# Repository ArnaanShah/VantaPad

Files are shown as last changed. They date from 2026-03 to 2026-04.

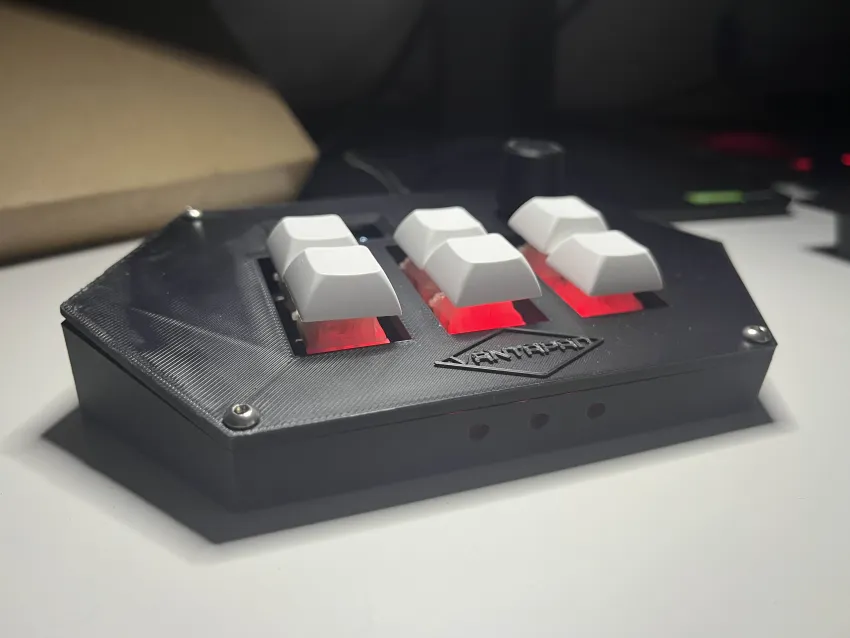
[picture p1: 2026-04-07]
ImagesVideos/IMG_0888.webp

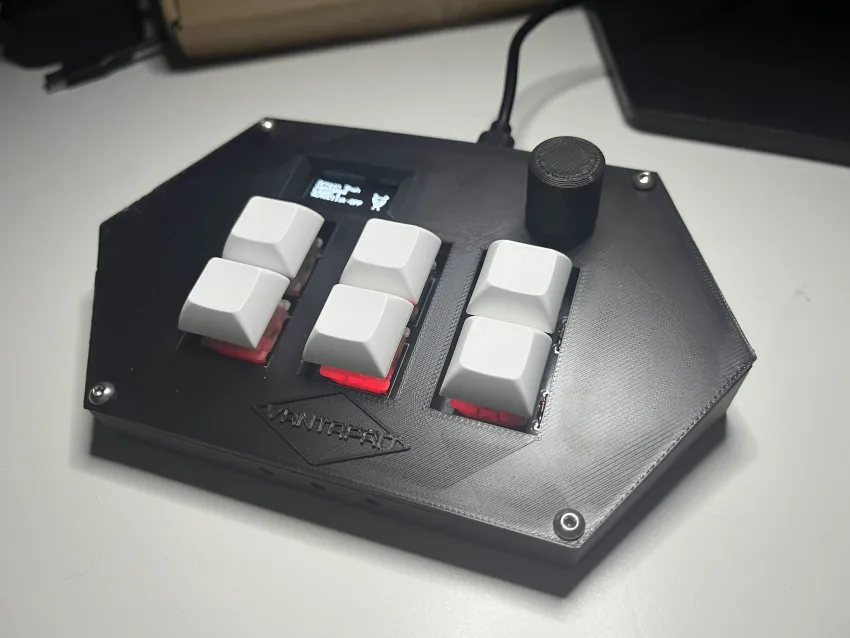
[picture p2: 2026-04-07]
ImagesVideos/IMG_0889.webp

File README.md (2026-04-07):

# VantaPad 👽

VantaPadLogoImage
isoCompletedBuild

A Hackpad made as a part of [Hackclub's Blueprint](https://blueprint.hackclub.com/home) program. VantaPad is a sleek black macropad I will use for controlling simple functions on my computer that I currently do by hand. It is one of my first hardware projects and I built it so I could learn many valuable skills such as schematic design, PCB design, Firmware programming, and more.

## How to use
**Brief intro on how to get up and running with VantaPad**

1. Order all the parts based off the BOM
2. Solder your electrical components onto your PCB based on the models and schematics
3. Assemble your case using the hardware provided
4. Plug your microcontroller into your computer and flash your firmware
5. You're done! Read the rest of this doc to understand what it can do.

## Features 
**What I included on my build.**

- Black Case - A case in the shape of a hexagon with the logo embossed near the bottom.
- 6 Keys in 3x2 layout - Top row is used for resetting screen, taking screenshots, and play/pause. Bottom row has macros for reopening tabs, auto clicking, and cycling layers.  
- 3 RGB LEDs - Lights up a constant looping effect that fades in and out through the case. 
- Rotary Encoder - Layer 1 is Volume, Layer 2 is Tab Scrolling, Layer 3 is undo/redo
- 128x32 OLED Display - Shows important info like what layer you're on and auto clicker status. Also, shows idle animations and reactions when you press a key.
  
## PCB 
**The design around my PCB. This Includes the schematic I made, the PCB, and more.** 

I designed my PCB in KiCad 9.0! It was fun to use this app because it was pretty beginner friendly and intuitive. It also had some extra built in features so I didn't have to download another app.

Schematic: 

SchematicImage 

PCB:

PCBImage

3d VIEW:

Top3dPCBImage
Bottom3dPCBImage

I used KiCad's built-in Image Converter to make a footprint of my logo:

LogoFootprintImage

## CAD
**The CAD model I made.**

I modeled this project in Fusion 360 because I've used it before. My plan is that I can assemble the whole thing with 6 screws. 4 on the actual case and 2 connecting the PCB and PCB plate to the case. I added a 10 degree tilt to make it easier to see. There are 3 separate 3d printed parts; the top, the plate, and the bottom. The top has the VantaPad logo on it because it looks lit. 😎

Pictures 📸:
VantaPadAngledImage
VantaPadIsometricImage
VantaPadFrontTopImage
VantaPadTopImage

## Firmware 
**Insight into the Firmware**

I wrote all the firmware in QMK. I spent a long time fixing problems when writing the code. These problems were things like the firmware not compiling, not knowing how to use all my extra features, and more. The QMK docs can be confusing but I found many resources online to help me. 

- The 6 keys are mapped as shown but can be easily changed
```
║ Screen Reset ║ Screenshot   ║ Play/Pause  ║

║ Reopen Tab   ║ Auto Clicker ║ Layer Cycle ║
```
```// ---------- Keymaps ----------
const uint16_t PROGMEM keymaps[][MATRIX_ROWS][MATRIX_COLS] = {
    [_BASE] = LAYOUT(
        RESET_SCREEN, SCREENSHOT, KC_MPLY, KC_MUTE, // Top row + Encoder Button
        REOPEN_TAB, AUTO_CLICKER, KC_CYCLE_LAYERS
    ),
};
```
- The rotary encoder controls volume on the first layer, scrolls through browser tabs on the second layer, and undos/redos on the third layer.
  - When you press down on the encoder it always mutes the volume
```
const uint16_t PROGMEM encoder_map[][1][2] = {
    [_BASE]   = { ENCODER_CCW_CW(KC_VOLD, KC_VOLU) },
    [_LAYER1] = { ENCODER_CCW_CW(LCTL(KC_PGUP), LCTL(KC_PGDN)) },
    [_LAYER2] = { ENCODER_CCW_CW(LCTL(KC_Z), LCTL(KC_Y)) },
};
```
- The OLED has 2 animations. Animation 1 is the constant looping animation where my alien is "breathing" with occasional blinks. Animation 2 starts when any key is pressed and it basically makes the alien look surprised and have a lightning bolt above his head. 
OLEDAnimationImage

- The OLED also has some info on the left of the animation. This includes what layer it is currently using, whether the auto clicker is on, the label "Vantapad", and also my name. 
```
oled_set_cursor(0, 0);
    oled_write_P(PSTR("Arnaan Shah"), false);

    oled_set_cursor(0, 1);
    oled_write_P(PSTR("Vantapad"), false);

    oled_set_cursor(0, 2);
    switch (get_highest_layer(layer_state)) {
        case _BASE:   oled_write_P(PSTR("Layer 1"), false); break;
        case _LAYER1: oled_write_P(PSTR("Layer 2"), false); break;
        case _LAYER2: oled_write_P(PSTR("Layer 3"), false); break;
    }

    oled_set_cursor(0, 3);
    if (auto_clicker_active) {
        oled_write_P(PSTR("AutoClick:ON "), false);
    } else {
        oled_write_P(PSTR("AutoClick:OFF"), false);
    }
```

- The RGB LEDS are set to display red and cycle a constant breathing animation
```
void keyboard_post_init_user(void) {
    rgblight_enable_noeeprom();
    rgblight_sethsv_noeeprom(0, 255, 100);
    rgblight_mode_noeeprom(RGBLIGHT_MODE_BREATHING + 1); 
}
```
## BOM
**What to buy to build this macropad. Does not include all the tools required to build it.**

| Name | Amount | Link |
|---|---|---|
| Cherry MX Switches | 6 | [Adafruit](https://www.adafruit.com/product/4952)|
| DSA Keycaps | 6 | [Adafruit](https://www.adafruit.com/product/4997?srsltid=AfmBOopDyFMg5RxxF-Evr6nBGQDyHVTH-dyfbuGdqPaHn7PWQv5c8-_Q) |
| M3 16mm SHCS Bolts | 5 | [Accu Components](https://accu-components.com/us/metric-cap-head-screws/3822-SSCF-M3-16-A2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) |
| M3 12mm SHCS Bolt | 1 | [Accu Components](https://accu-components.com/us/metric-cap-head-screws/3820-SSCF-M3-12-A2) |
| M3 Hex Nuts | 6 | [Accu Components](https://accu-components.com/us/hexagon-nuts/7888-HPN-M3-A2) |
| In4148 DO-35 Diodes | 7 | [Adafruit](https://www.adafruit.com/product/1641?srsltid=AfmBOoragpyopdxH587co8w9Kl0W3cZMjn9bZIbP4UEYHfyiLFoC3nJv) |
| WS2812B RGB LEDS | 3 | [Adafruit](https://www.adafruit.com/product/4684?srsltid=AfmBOop-1QOhPkmYg3AzDhOUYgR5UXpQo03Vo2tT4txB9Lo8MBpf2Z1e) |
| 0.91" OLED Display | 1 | [Aliexpress](https://www.aliexpress.us/item/3256807215355950.html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)|
| EC11 Encoder | 1 | [Adafruit](https://www.adafruit.com/product/377)|
| Seeed Studio XIAO RP2040 | 1 | [Seeed Studio](https://www.seeedstudio.com/XIAO-RP2040-v1-0-p-5026.html) |
| 3d Printed Case | 1 | N/A |

## Extras 🪄
**Miscellaneous related things**

I made the logo design all in Figma and it's based off the "Space Alien" inside Halloween Stickers. 

It's honestly one of my favorite parts of the project because of how cute he is 😅

_

Here are some photos of my brainstorming process. It includes some (really) rough sketches in my notebook and also online. 



_I always start with doing things in my notebook and then move forward from there. It helps me get a very basic idea of what im going to do and how to accomplish it._


 
_I made this image afterwards just to get a better understanding of how I wanted it to look._

Changes I would still consider making down the line include: 
1. More Information displayed on the OLED - WPM, Time, Date, Volume
2. Adding more animations to the OLED - Spinning alien based on knob, startup screen
3. Making the RGB react - Flash on key press, blink when auto-clicker's active
4. Displaying the PCB through the case somehow

Some resources I used:
- [Joe Scotto's Youtube Channel](https://www.youtube.com/@joe_scotto) (LIFESAVER 🙏)
- [QMK Docs](https://docs.qmk.fm)
- [r/MechanicalKeyboards subreddit](https://www.reddit.com/r/MechanicalKeyboards/) 

# Thanks for reading! If you have any feedback, comments, or questions I would love to hear them and you can always reach out to me!
GoodbyeImage

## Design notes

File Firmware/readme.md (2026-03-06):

# vantapad

vantapad

A Hackpad made as a part of Hackclub's Blueprint program. VantaPad is a sleek black macropad I will use for controlling simple functions on my computer that I currently do by hand. It is one of my first hardware projects and it taught me many valuable skills such as schematic design, PCB design, Firmware programming, and more.

* Keyboard Maintainer: [Arnaan Shah](https://github.com/ArnaanShah)

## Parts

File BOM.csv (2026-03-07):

Name | Amount | Link
Cherry MX Switches | 6 | https://www.adafruit.com/product/4952
DSA Keycaps | 6 | https://www.adafruit.com/product/4997
M3 16mm SHCS Bolts | 5 | https://accu-components.com/us/metric-cap-head-screws/3822-SSCF-M3-16-A2
M3 12mm SHCS Bolt | 1 | https://accu-components.com/us/metric-cap-head-screws/3820-SSCF-M3-12-A2
M3 Hex Nuts | 6 | https://accu-components.com/us/hexagon-nuts/7888-HPN-M3-A2
In4148 DO-35 Diodes | 7 | https://www.adafruit.com/product/1641
WS2812B RGB LEDS | 3 | https://www.adafruit.com/product/4684
0.91 OLED Display | 1 | https://www.aliexpress.us/item/3256807215355950.html?src=google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
EC11 Encoder | 1 | https://www.adafruit.com/product/377
Seeed Studio XIAO RP2040 | 1 | https://www.seeedstudio.com/XIAO-RP2040-v1-0-p-5026.html
3d Printed Case | 1 | N/A

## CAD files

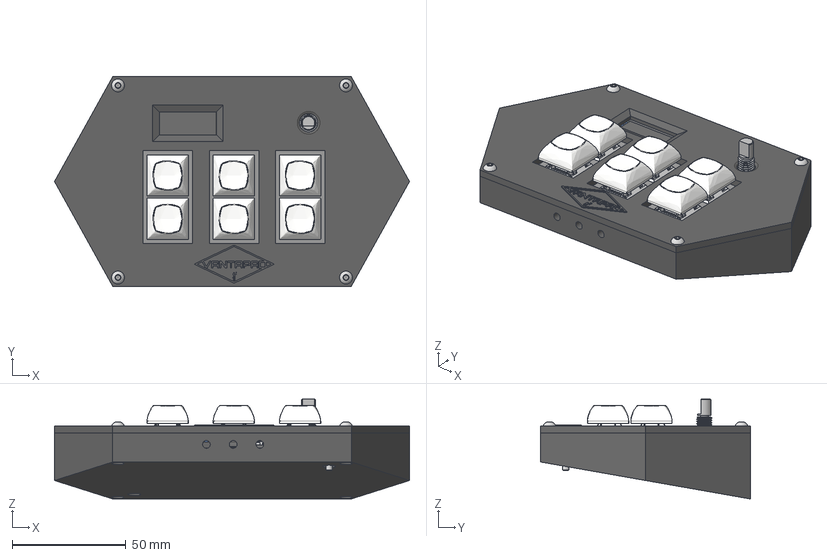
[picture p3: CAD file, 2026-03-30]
CAD/VantaPad v1.step
155.8 x 92.0 x 43.8 mm
MX_CAD x 6
PinHeader_1x04_P2.54mm_Vertical
OLED_0.91_128x32
Pin Header 4 x 1 TH 2.54mm Pitch
RESC-0603 x 13
2SD0601A
EC11
D_DO-35_SOD27_P7.62mm_Horizontal x 7
arnaansRealMacropad_silkscreen
arnaansRealMacropad_silkscreen_1
arnaansRealMacropad_soldermask
arnaansRealMacropad_soldermask_1
arnaansRealMacropad_PCB
MX Mount v1 x 6
type-c v2
smd_button v3
DOUT
DIN
VSS
VDD
smd_button v3(Mirror)
Logo
DIN EN ISO 7380-1 - M3 x 16 Steel 4.6 Plain x 6

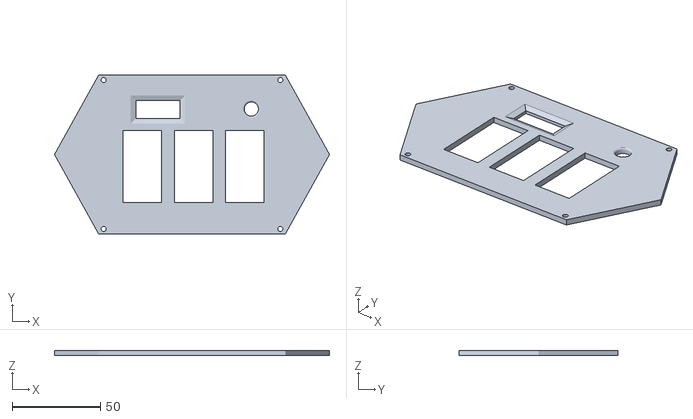
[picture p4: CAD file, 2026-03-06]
Production/VantaPadV1Top.stl
155.8 x 90.0 x 3.00

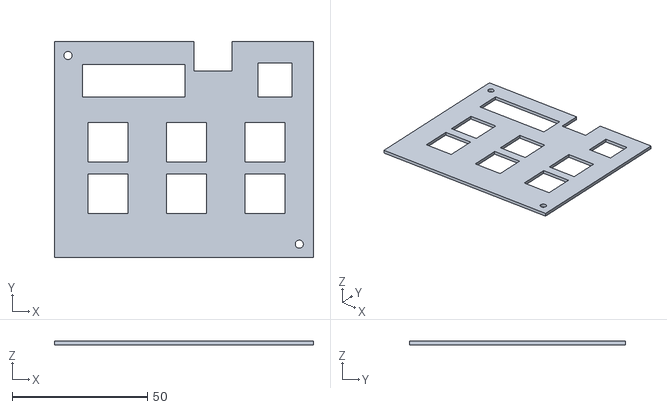
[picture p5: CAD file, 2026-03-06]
Production/VantaPadV1Plate.stl
95.8 x 80.0 x 1.50

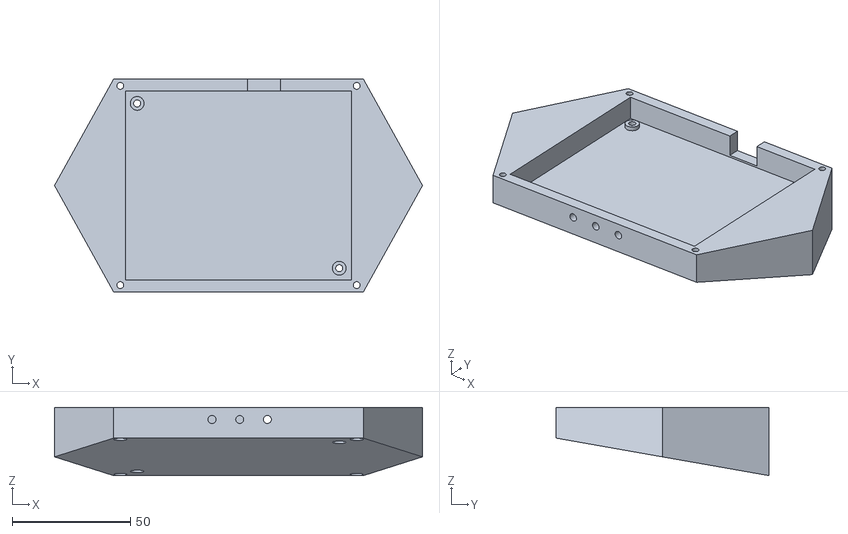
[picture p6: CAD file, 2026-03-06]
Production/VantaPadV1Bottom.stl
155.8 x 90.0 x 28.9

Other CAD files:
CAD/VantaPad v1.3mf

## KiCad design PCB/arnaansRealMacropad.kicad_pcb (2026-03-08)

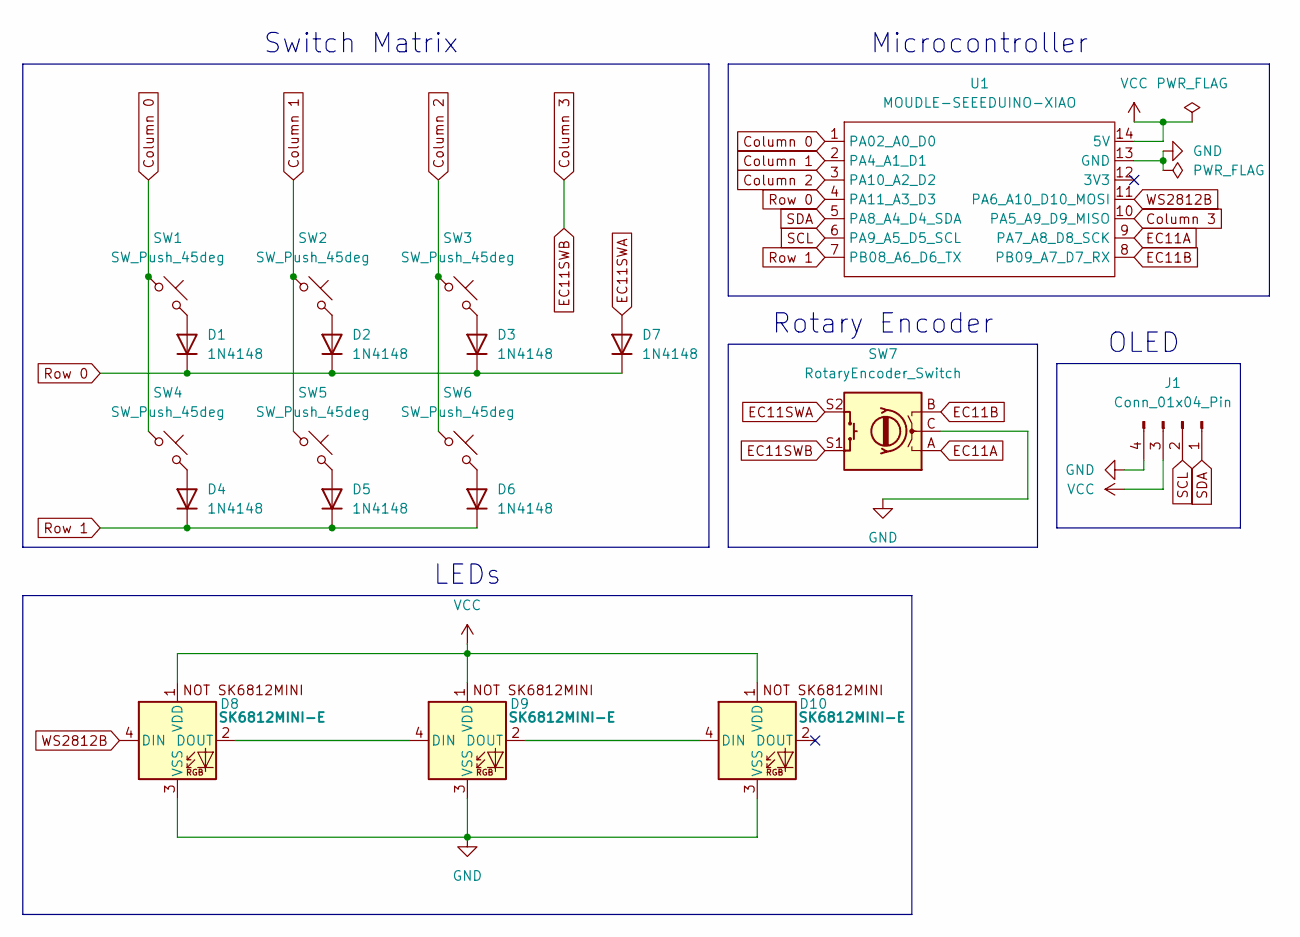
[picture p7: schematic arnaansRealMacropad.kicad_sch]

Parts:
D1, D2, D3, D4, D5, D6, D7: 1N4148; D_DO-35_SOD27_P7.62mm_Horizontal
D8, D9, D10: SK6812MINI-E; SK6812MINI-E_fixed
J1: Conn_01x04_Pin; PinHeader_1x04_P2.54mm_Vertical
SW1, SW2, SW3, SW4, SW5, SW6: SW_Push_45deg; SW_Cherry_MX_1.00u_PCB
SW7: RotaryEncoder_Switch; RotaryEncoder_Alps_EC11E-Switch_Vertical_H20mm
U1: MOUDLE-SEEEDUINO-XIAO; XIAO-Generic-Hybrid-14P-2.54-21X17.8MM

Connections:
Column 0: SW1.1, SW4.1, U1.1 (PA02_A0_D0)
Column 1: SW2.1, SW5.1, U1.2 (PA4_A1_D1)
Column 2: SW3.1, SW6.1, U1.3 (PA10_A2_D2)
Column 3: SW7.S1, U1.10 (PA5_A9_D9_MISO)
EC11A: SW7.A, U1.9 (PA7_A8_D8_SCK)
EC11B: SW7.B, U1.8 (PB09_A7_D7_RX)
EC11SWA: D7.2 (A), SW7.S2
GND: D8.3 (VSS), D9.3 (VSS), D10.3 (VSS), J1.4, SW7.C, U1.13 (GND)
unnamed: D1.2 (A), SW1.2
unnamed: D2.2 (A), SW2.2
unnamed: D3.2 (A), SW3.2
unnamed: D4.2 (A), SW4.2
unnamed: D5.2 (A), SW5.2
unnamed: D6.2 (A), SW6.2
unnamed: D8.2 (DOUT), D9.4 (DIN)
unnamed: D9.2 (DOUT), D10.4 (DIN)
Row 0: D1.1 (K), D2.1 (K), D3.1 (K), D7.1 (K), U1.4 (PA11_A3_D3)
Row 1: D4.1 (K), D5.1 (K), D6.1 (K), U1.7 (PB08_A6_D6_TX)
SCL: J1.2, U1.6 (PA9_A5_D5_SCL)
SDA: J1.1, U1.5 (PA8_A4_D4_SDA)
VCC: D8.1 (VDD), D9.1 (VDD), D10.1 (VDD), J1.3, U1.14 (5V)
WS2812B: D8.4 (DIN), U1.11 (PA6_A10_D10_MOSI)

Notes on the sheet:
Rotary Encoder
OLED
Microcontroller
Switch Matrix
LEDs

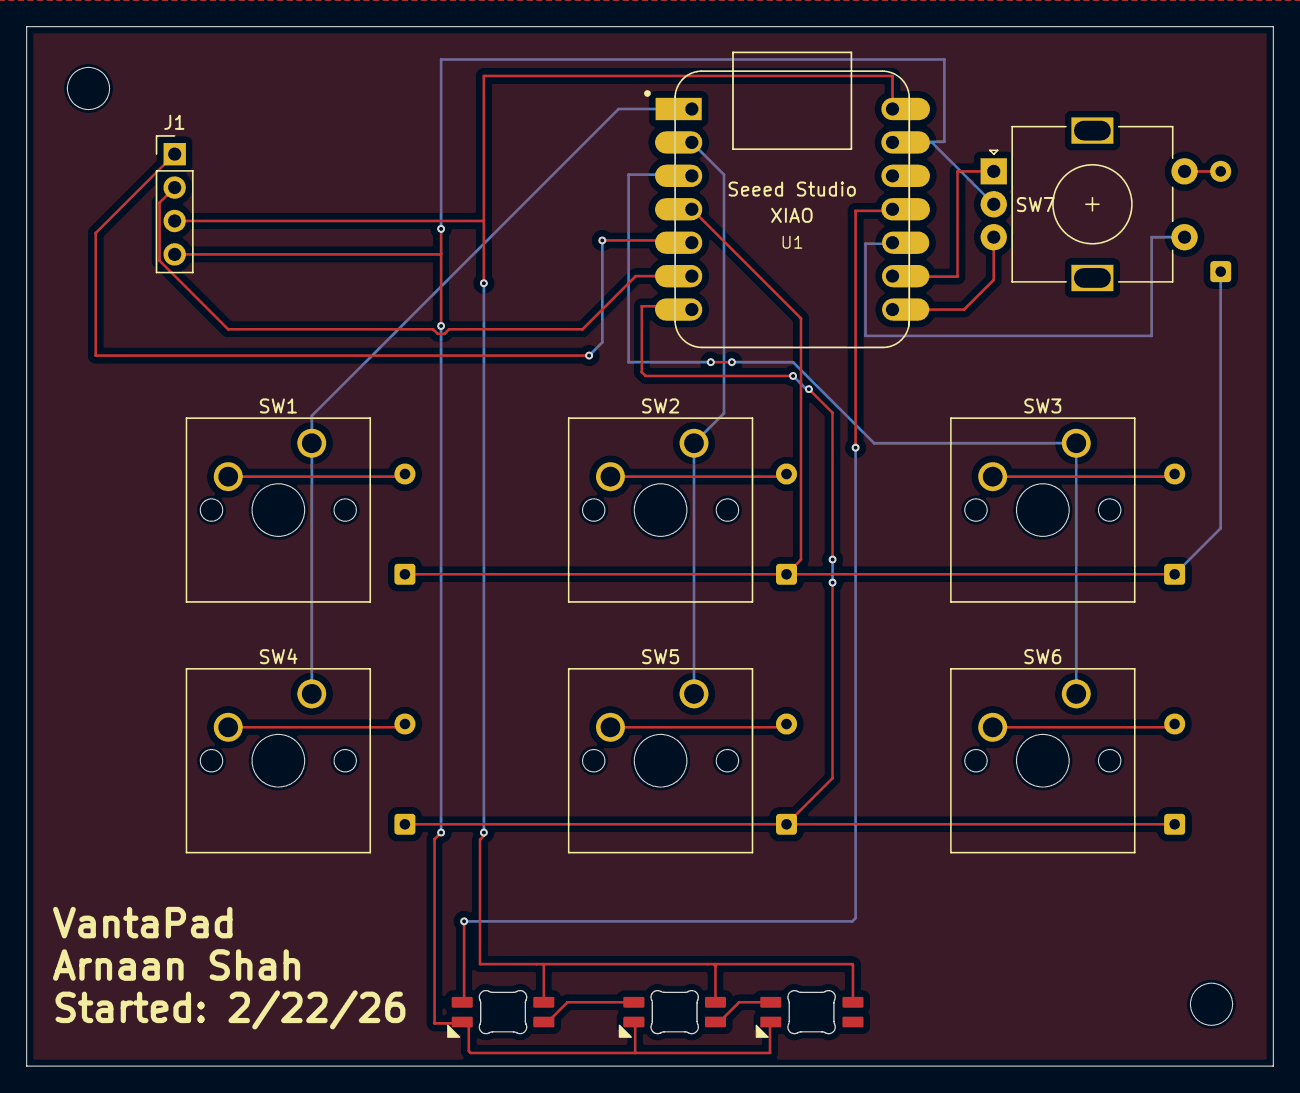
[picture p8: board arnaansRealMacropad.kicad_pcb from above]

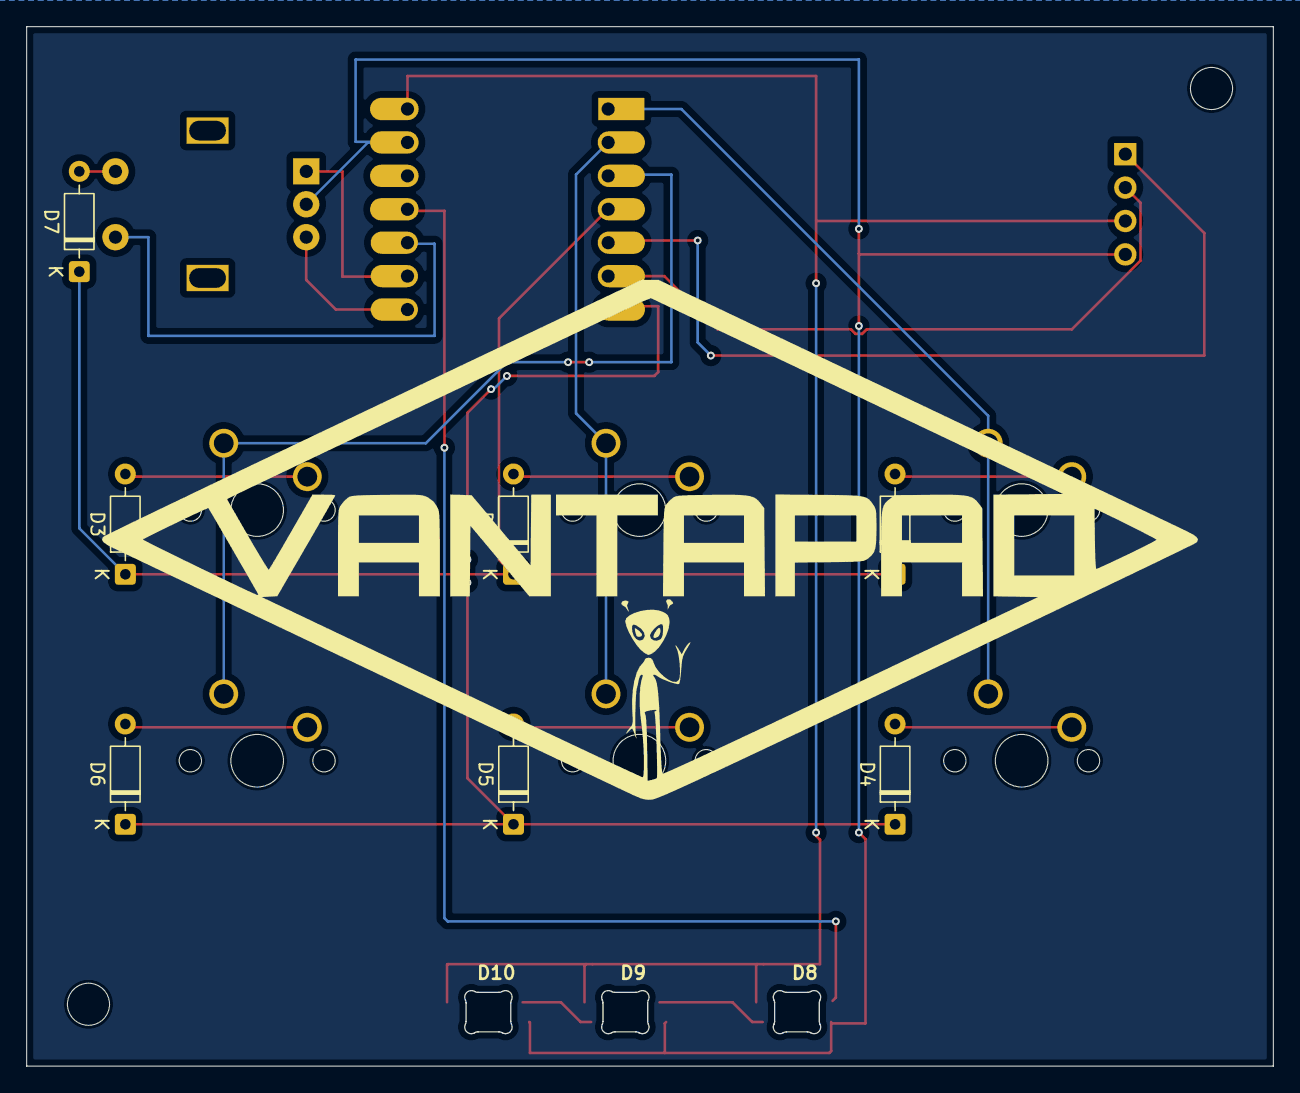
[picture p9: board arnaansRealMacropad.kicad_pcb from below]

Board: 2 copper layers, 94.8 x 79.0 mm, 19 parts (10 on the bottom side), 22 nets.

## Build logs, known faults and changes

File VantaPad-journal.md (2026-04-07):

<!--
  This journal is auto generated by Hack Club Blueprint.
-->

# 3/30/2026 - Adjusted CAD Model Slightly and Printed Case  

_Time spent: 1.2h_  

After finishing my design, I had to wait a while for all the parts to get shipped. So, I decided to start printing the case. 

When I threw the model in my slicer, I noticed that some of the walls were extremely thin, which would have caused issues later on. I went into Fusion 360 and used the Press/Pull modifier to fix this and make them 1mm thicker.


I then began printing it using the 0.08mm High Quality print profile in Bambu Studio.


# 3/31/2026 - Soldered switches, diodes, and encoder  

_Time spent: 2.0h_  

This session I spent some time soldering the easiest components, the switches, the diodes, and the encoder.

I started with the switches and the first one took me a while but then I understood and got quicker. 

Then moving onto the diodes I first placed them into the board in the correct orientation and then bent the leads so they would stay in place. 

Finally I soldered the encoder. I first held it down using some tape so I could solder the mounting tabs, then I removed it to solder the rest. 

Then I was done!


# 4/4/2026 - Soldered microcontroller, OLED, and LEDS + Tested Current  

_Time spent: 4.5h_  

This session I spent a long time getting the rest of the components soldered onto the PCB. 

I think it took so long because of how many connections there were and because I had to learn how to solder surface mounted components.

I first soldered all the header pins to the board, then the components to the header pins, and finally the LEDS to their pads.



After that, I used a multimeter to test all the connections and ensure they were solid and fixed those that weren't.  

# 4/5/2026 - Flashing Firmware and Debugging Encoder  

_Time spent: 3.0h_  

This session I flashed my first firmware onto the macropad and also managed to debug some things that weren't working. 

After the first flash I was pleased to see that a majority of the functions worked. All the keys worked flawlessly and the RGBs were breathing which looked awesome. However, both the rotations on the encoder and the OLED display weren't doing anything.

I decided to work on fixing the encoder first because it seemed simpler. After doing some research, I figured out that I just had to change the resolution and add debounce in Keyboard.json. When I was testing, the rotations were backwards so I swapped the encoder pins. 


And then it worked amazingly! I was really happy and now I could use it for volume, tab scrolling, and undo/redo.  

I still need to fix the OLED display, but after that everything should work properly.

# 4/6/2026 - Completed! - Finishing Firmware and Debugging OLED  

_Time spent: 5.0h_  

This session I focused on getting my OLED to work and finishing up the firmware.

I left off with almost everything working except the OLED. I spent what felt like forever looking through the QMK docs and random forum posts about OLED displays. 

After not finding a solution, I asked the #blueprint channel in the slack and received many helpful replies that led me to attempt a test using a basic sketch and the arduino IDE just to check if the OLED was working. 



And it worked! It was properly displaying text on the screen. So, I continued on trying to make it work with the QMK firmware.

After looking into specific documentation for the rp2040 and it's i2c configuration, I figured out that I needed to explicitly define things in my config.h for it to work.



And after flashing, it was working amazingly! I was thrilled to see my name, the layer count, and my alien animation all on the screen. 

However, after testing some more, I realized I could be doing more with the screen. I then decided to add the label "Vantapad" and the autoclicker status to the screen. Additionally, I added more frames to the animation to make it look much smoother. 



And then I was done! I had a fully working VantaPad 🥹




I'm thrilled with everything I learned and really think this has had great benefits on me. I'll forever be happy when I look down and see a little alien looking back up at me.

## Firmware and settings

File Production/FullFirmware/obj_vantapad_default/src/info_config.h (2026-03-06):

// Copyright 2026 QMK
// SPDX-License-Identifier: GPL-2.0-or-later

/*******************************************************************************
  88888888888 888      d8b                .d888 d8b 888               d8b
      888     888      Y8P               d88P"  Y8P 888               Y8P
      888     888                        888        888
      888     88888b.  888 .d8888b       888888 888 888  .d88b.       888 .d8888b
      888     888 "88b 888 88K           888    888 888 d8P  Y8b      888 88K
      888     888  888 888 "Y8888b.      888    888 888 88888888      888 "Y8888b.
      888     888  888 888      X88      888    888 888 Y8b.          888      X88
      888     888  888 888  88888P'      888    888 888  "Y8888       888  88888P'
                                                        888                 888
                                                        888                 888
                                                        888                 888
     .d88b.   .d88b.  88888b.   .d88b.  888d888 8888b.  888888 .d88b.   .d88888
    d88P"88b d8P  Y8b 888 "88b d8P  Y8b 888P"      "88b 888   d8P  Y8b d88" 888
    888  888 88888888 888  888 88888888 888    .d888888 888   88888888 888  888
    Y88b 888 Y8b.     888  888 Y8b.     888    888  888 Y88b. Y8b.     Y88b 888
     "Y88888  "Y8888  888  888  "Y8888  888    "Y888888  "Y888 "Y8888   "Y88888
         888
    Y8b d88P
     "Y88P"
*******************************************************************************/

#pragma once

#ifndef DIODE_DIRECTION
#    define DIODE_DIRECTION COL2ROW
#endif // DIODE_DIRECTION

#ifndef RGBLIGHT_LED_COUNT
#    define RGBLIGHT_LED_COUNT 3
#endif // RGBLIGHT_LED_COUNT

#ifndef RGBLIGHT_DEFAULT_HUE
#    define RGBLIGHT_DEFAULT_HUE 0
#endif // RGBLIGHT_DEFAULT_HUE

#ifndef RGBLIGHT_DEFAULT_SAT
#    define RGBLIGHT_DEFAULT_SAT 255
#endif // RGBLIGHT_DEFAULT_SAT

#ifndef RGBLIGHT_DEFAULT_VAL
#    define RGBLIGHT_DEFAULT_VAL 100
#endif // RGBLIGHT_DEFAULT_VAL

#ifndef RGB_DI_PIN
#    define RGB_DI_PIN GP3
#endif // RGB_DI_PIN

#ifndef RGBW
#    define RGBW True
#endif // RGBW

#ifndef DEVICE_VER
#    define DEVICE_VER 0x0100
#endif // DEVICE_VER

#ifndef MANUFACTURER
#    define MANUFACTURER "Arnaan Shah"
#endif // MANUFACTURER

#ifndef PRODUCT
#    define PRODUCT "vantapad"
#endif // PRODUCT

#ifndef PRODUCT_ID
#    define PRODUCT_ID 0x0001
#endif // PRODUCT_ID

#ifndef VENDOR_ID
#    define VENDOR_ID 0xFEED
#endif // VENDOR_ID

#ifndef MATRIX_COLS
#    define MATRIX_COLS 4
#endif // MATRIX_COLS

#ifndef MATRIX_ROWS
#    define MATRIX_ROWS 2
#endif // MATRIX_ROWS

#ifndef MATRIX_COL_PINS
#    define MATRIX_COL_PINS { GP26, GP27, GP28, GP4 }
#endif // MATRIX_COL_PINS

#ifndef MATRIX_ROW_PINS
#    define MATRIX_ROW_PINS { GP29, GP0 }
#endif // MATRIX_ROW_PINS

#ifndef ENCODER_A_PINS
#    define ENCODER_A_PINS { GP2 }
#endif // ENCODER_A_PINS

#ifndef ENCODER_B_PINS
#    define ENCODER_B_PINS { GP1 }
#endif // ENCODER_B_PINS

#ifndef ENCODER_RESOLUTION
#    define ENCODER_RESOLUTION 4
#endif // ENCODER_RESOLUTION

#ifndef RGBLIGHT_EFFECT_BREATHING
#    define RGBLIGHT_EFFECT_BREATHING
#endif // RGBLIGHT_EFFECT_BREATHING

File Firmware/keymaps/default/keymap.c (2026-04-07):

// Copyright 2023 QMK
// SPDX-License-Identifier: GPL-2.0-or-later
#include QMK_KEYBOARD_H

enum custom_keycodes {
    REOPEN_TAB = SAFE_RANGE,
    AUTO_CLICKER,
    KC_CYCLE_LAYERS,
    RESET_SCREEN,
    SCREENSHOT
};

enum layer_names {
    _BASE,
    _LAYER1,
    _LAYER2
};

#define LAYER_CYCLE_START 0
#define LAYER_CYCLE_END   2

//  Auto Clicker 
static bool     auto_clicker_active = false;
static uint32_t auto_clicker_timer  = 0;
#define AUTO_CLICK_INTERVAL_MS 20

// Shock Logic
#define SHOCK_DURATION_MS 750
static bool     shock_active  = false;
static uint32_t shock_timer   = 0;


bool process_record_user(uint16_t keycode, keyrecord_t *record) {
    if (record->event.pressed) {
        shock_active = true;
        shock_timer  = timer_read32();
    }
    
    switch (keycode) {
        case REOPEN_TAB:
            if (record->event.pressed) {
                SEND_STRING(SS_LCTL(SS_LSFT("t")));
            }
            return false;
        case AUTO_CLICKER:
            if (record->event.pressed) {
                auto_clicker_active = !auto_clicker_active;
                auto_clicker_timer  = timer_read32();
            }
            return false;
        case KC_CYCLE_LAYERS:
            if (record->event.pressed) {
                uint8_t current_layer = get_highest_layer(layer_state);
                uint8_t next_layer = (current_layer >= LAYER_CYCLE_END) ? LAYER_CYCLE_START : current_layer + 1;
                layer_move(next_layer);
            }
            return false;
        case RESET_SCREEN:
            if (record->event.pressed) {
                SEND_STRING(SS_LCTL("w"));
                SEND_STRING(SS_LCTL("t"));
                tap_code(KC_MUTE); 
            }
            return false;
        case SCREENSHOT:
            if (record->event.pressed) {
                SEND_STRING(SS_LWIN(SS_LSFT("s")));
            }
            return false;
    }
    return true;
}

// Autoclicker tick
void housekeeping_task_user(void) {
    if (auto_clicker_active && timer_elapsed32(auto_clicker_timer) >= AUTO_CLICK_INTERVAL_MS) {
        auto_clicker_timer = timer_read32();
        tap_code(MS_BTN1);
    }
}

// RGB initialization
void keyboard_post_init_user(void) {
    rgblight_enable_noeeprom();
    rgblight_sethsv_noeeprom(0, 255, 100); // red
    rgblight_mode_noeeprom(RGBLIGHT_MODE_BREATHING + 2); // speed 2
}

#if defined(ENCODER_MAP_ENABLE)
const uint16_t PROGMEM encoder_map[][1][2] = {
    [_BASE]   = { ENCODER_CCW_CW(KC_VOLD, KC_VOLU) },
    [_LAYER1] = { ENCODER_CCW_CW(LCTL(KC_PGUP), LCTL(KC_PGDN)) },
    [_LAYER2] = { ENCODER_CCW_CW(LCTL(KC_Z), LCTL(KC_Y)) },
};
#endif

// OLED 
#ifdef OLED_ENABLE

//Bitmap images
static const char epd_bitmap_Small__1_[] PROGMEM = {
    0x00, 0x00, 0x00, 0x00, 0x00, 0x00, 0x00, 0x00, 0x00, 0x00, 0x00, 0x00, 0x00, 0x80, 0x40, 0x00,
    0xc0, 0x00, 0x00, 0x00, 0x00, 0x00, 0x00, 0x00, 0x00, 0x00, 0x00, 0x00, 0x80, 0x40, 0x00, 0x40,
    0x80, 0x00, 0x00, 0x00, 0x00, 0x00, 0x00, 0x00, 0x00, 0x00, 0x00, 0x00, 0x00, 0x00, 0x00, 0x00,
    0x00, 0x00, 0x00, 0x00, 0x00, 0x00, 0x00, 0x00, 0x00, 0x00, 0x01, 0xe0, 0xb2, 0x1f, 0x08, 0x08,
    0x04, 0x04, 0x04, 0x04, 0x04, 0x04, 0x04, 0x04, 0x84, 0x0c, 0x0f, 0xf6, 0x01, 0x01, 0x00, 0x00,
    0x00, 0x00, 0x00, 0x00, 0x00, 0x00, 0x00, 0x00, 0x00, 0x00, 0x00, 0x00, 0x00, 0x00, 0x00, 0x00,
    0x00, 0x00, 0x00, 0x00, 0x00, 0x00, 0x00, 0x00, 0x00, 0x03, 0x0c, 0x10, 0x6f, 0x89, 0x1a, 0x0e,
    0x40, 0x40, 0x1e, 0x13, 0x99, 0x4f, 0x30, 0x0c, 0x03, 0x00, 0x00, 0x00, 0x00, 0x00, 0x00, 0x00,
    0x00, 0x00, 0x00, 0x00, 0x00, 0x00, 0x00, 0x00, 0x00, 0x00, 0x00, 0x00, 0x00, 0x00, 0x00, 0x00,
    0x00, 0x00, 0x00, 0x00, 0x00, 0x00, 0x00, 0x00, 0x00, 0xc0, 0x20, 0x91, 0x0f, 0x02, 0x02, 0x06,
    0x09, 0x30, 0xe0, 0x00, 0x00, 0x00, 0x00, 0x00, 0x00, 0x00, 0x00, 0x00, 0x00, 0x00, 0x00, 0x00,
    0x00, 0x00, 0x00, 0x00
};

static const char epd_bitmap_SemiSmall__2_[] PROGMEM = {
    0x00, 0x00, 0x00, 0x00, 0x00, 0x00, 0x00, 0x00, 0x00, 0x00, 0x00, 0x00, 0xe0, 0x20, 0x20, 0xe0, 
    0x00, 0x00, 0x00, 0x00, 0x00, 0x00, 0x00, 0x00, 0x00, 0x00, 0x00, 0x00, 0xe0, 0xa0, 0xa0, 0xe0, 
    0xc0, 0x00, 0x00, 0x00, 0x00, 0x00, 0x00, 0x00, 0x00, 0x00, 0x00, 0x00, 0x00, 0x00, 0x00, 0x00, 
    0x00, 0x00, 0x00, 0x00, 0x00, 0x00, 0x00, 0x00, 0x00, 0x00, 0xf1, 0x9b, 0x0f, 0x06, 0x84, 0x86, 
    0x06, 0x02, 0x02, 0x02, 0x02, 0x02, 0x86, 0x86, 0x86, 0x06, 0x0f, 0xf9, 0x00, 0x00, 0x00, 0x00, 
    0x00, 0x00, 0x00, 0x00, 0x00, 0x00, 0x00, 0x00, 0x00, 0x00, 0x00, 0x00, 0x00, 0x00, 0x00, 0x00, 
    0x00, 0x00, 0x00, 0x00, 0x00, 0x00, 0x00, 0x00, 0x03, 0x0e, 0x1c, 0x6f, 0xc9, 0x89, 0x0e, 0x40, 
    0x40, 0x0e, 0x09, 0x88, 0xcf, 0x73, 0x18, 0x06, 0x01, 0x00, 0x00, 0x00, 0x00, 0x00, 0x00, 0x00, 
    0x00, 0x00, 0x00, 0x00, 0x00, 0x00, 0x00, 0x00, 0x00, 0x00, 0x00, 0x00, 0x00, 0x00, 0x00, 0x00, 
    0x00, 0x00, 0x00, 0x00, 0x00, 0x00, 0x00, 0x00, 0x80, 0x60, 0x99, 0x07, 0x03, 0x03, 0x07, 0x0f, 
    0x91, 0x60, 0x80, 0x00, 0x00, 0x00, 0x00, 0x00, 0x00, 0x00, 0x00, 0x00, 0x00, 0x00, 0x00, 0x00, 
    0x00, 0x00, 0x00, 0x00
};

static const char epd_bitmap_Medium__3_[] PROGMEM = {
    0x00, 0x00, 0x00, 0x00, 0x00, 0x00, 0x00, 0x00, 0x00, 0x00, 0x00, 0x70, 0xc8, 0xc8, 0xf8, 0x30, 
    0x00, 0x00, 0x00, 0x00, 0x00, 0x00, 0x00, 0x00, 0x00, 0x00, 0x00, 0x00, 0xf0, 0xc8, 0xc8, 0x78, 
    0x20, 0x00, 0x00, 0x00, 0x00, 0x00, 0x00, 0x00, 0x00, 0x00, 0x00, 0x00, 0x00, 0x00, 0x00, 0x00, 
    0x00, 0x00, 0x00, 0x00, 0x00, 0x00, 0x00, 0x00, 0x00, 0x38, 0xfd, 0x07, 0x07, 0xc2, 0xc3, 0x83, 
    0x81, 0x01, 0x01, 0x01, 0x01, 0x81, 0xc1, 0xc3, 0xc3, 0x03, 0x87, 0xfc, 0x00, 0x00, 0x00, 0x00, 
    0x00, 0x00, 0x00, 0x00, 0x00, 0x00, 0x00, 0x00, 0x00, 0x00, 0x00, 0x00, 0x00, 0x00, 0x00, 0x00, 
    0x00, 0x00, 0x00, 0x00, 0x00, 0x00, 0x00, 0x01, 0x07, 0x0c, 0x3b, 0x66, 0xcc, 0x8f, 0x07, 0x20, 
    0x00, 0x27, 0x8d, 0xcc, 0x67, 0x3f, 0x1e, 0x07, 0x01, 0x00, 0x00, 0x00, 0x00, 0x00, 0x00, 0x00, 
    0x00, 0x00, 0x00, 0x00, 0x00, 0x00, 0x00, 0x00, 0x00, 0x00, 0x00, 0x00, 0x00, 0x00, 0x00, 0x00, 
    0x00, 0x00, 0x00, 0x00, 0x00, 0x00, 0x00, 0x00, 0xe0, 0x30, 0x89, 0x07, 0x03, 0x03, 0x07, 0x0f, 
    0xb0, 0xe0, 0xc0, 0x00, 0x00, 0x00, 0x00, 0x00, 0x00, 0x00, 0x00, 0x00, 0x00, 0x00, 0x00, 0x00, 
    0x00, 0x00, 0x00, 0x00
};
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

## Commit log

2026-03-06 Added the required files
    [VantaPadV1Bottom.stl, VantaPadV1Plate.stl, VantaPadV1Top.stl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]
2026-03-07 Add BOM.csv with components and links
    [BOM.csv]
2026-03-08 Fixed LED footprint
    [arnaansRealMacropad.kicad_pcb, arnaansRealMacropad.kicad_sch]
2026-03-30 Fixed walls being too thin in CAD file
    [VantaPad v1.step]
2026-04-05 Fixing and debugging Firmware
    [VantaPad v1.3mf]
